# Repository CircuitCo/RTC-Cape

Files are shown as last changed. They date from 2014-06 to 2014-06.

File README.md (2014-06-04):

RTC-Cape
========
The RTC Cape provides time tracking capability for the BeagleBone Black even when the power is lost. This cape features the DS1338 I2C-based real-time clock/calendar and a holder for a coin battery type CR2032. Setup, reading, and setting up time is easy with the provided device tree overlay.

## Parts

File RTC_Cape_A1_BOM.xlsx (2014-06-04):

BOARD NAME: RTC CAPE
REVISION: A1 |  |  |  | LAST UPDATE: | 2014-04-04
PART NUMBER: 999-0004279
ITM | QTY | REF DESIGNATOR | PART NUMBER | DESCRIPTION | MANUFACTURER | MAN P/N
1 | 1 | PCB | 999-0004279 | RTC CAPE | CIRCUITCO
2 | 1 | BH1 | 253-0004977 | HOLDER COINCELL 2032 RETAINRCLIP | MPD | BS-7
3 | 1 | C1 | 123-0001047 | CAP CER 0.1UF 10V 10% X5R 0402 | MURATA | GRM155R61A104KA01
4 | 2 | P8, P9 | 235-0002217 | 46 POS,DUAL,GOLD,.1" | MLE | SSHQ-123-D-08-G-LF
5 | 3 | R1, R2, R3 | 110-0001987 | RES 2.2K OHM 1/16W 5% 0402 SMD | YAGEO | RC0402JR-072K2L
6 | 1 | R4 | RC0402JR-070RL | RES 0.0 OHM 1/16W JUMP 0402 SMD | YAGEO | RC0402JR-070RL
7 | 1 | U1 | 140-0004976 | IC RTC SERIAL 512K 8SOIC | MAXIM | DS1338Z-33+
8 | 1 | Y1 | 145-0003173 | CRYSTAL 32.768KHZ 12.5PF THRU | CITIZEN | CFS308-32.768KDZF-UB

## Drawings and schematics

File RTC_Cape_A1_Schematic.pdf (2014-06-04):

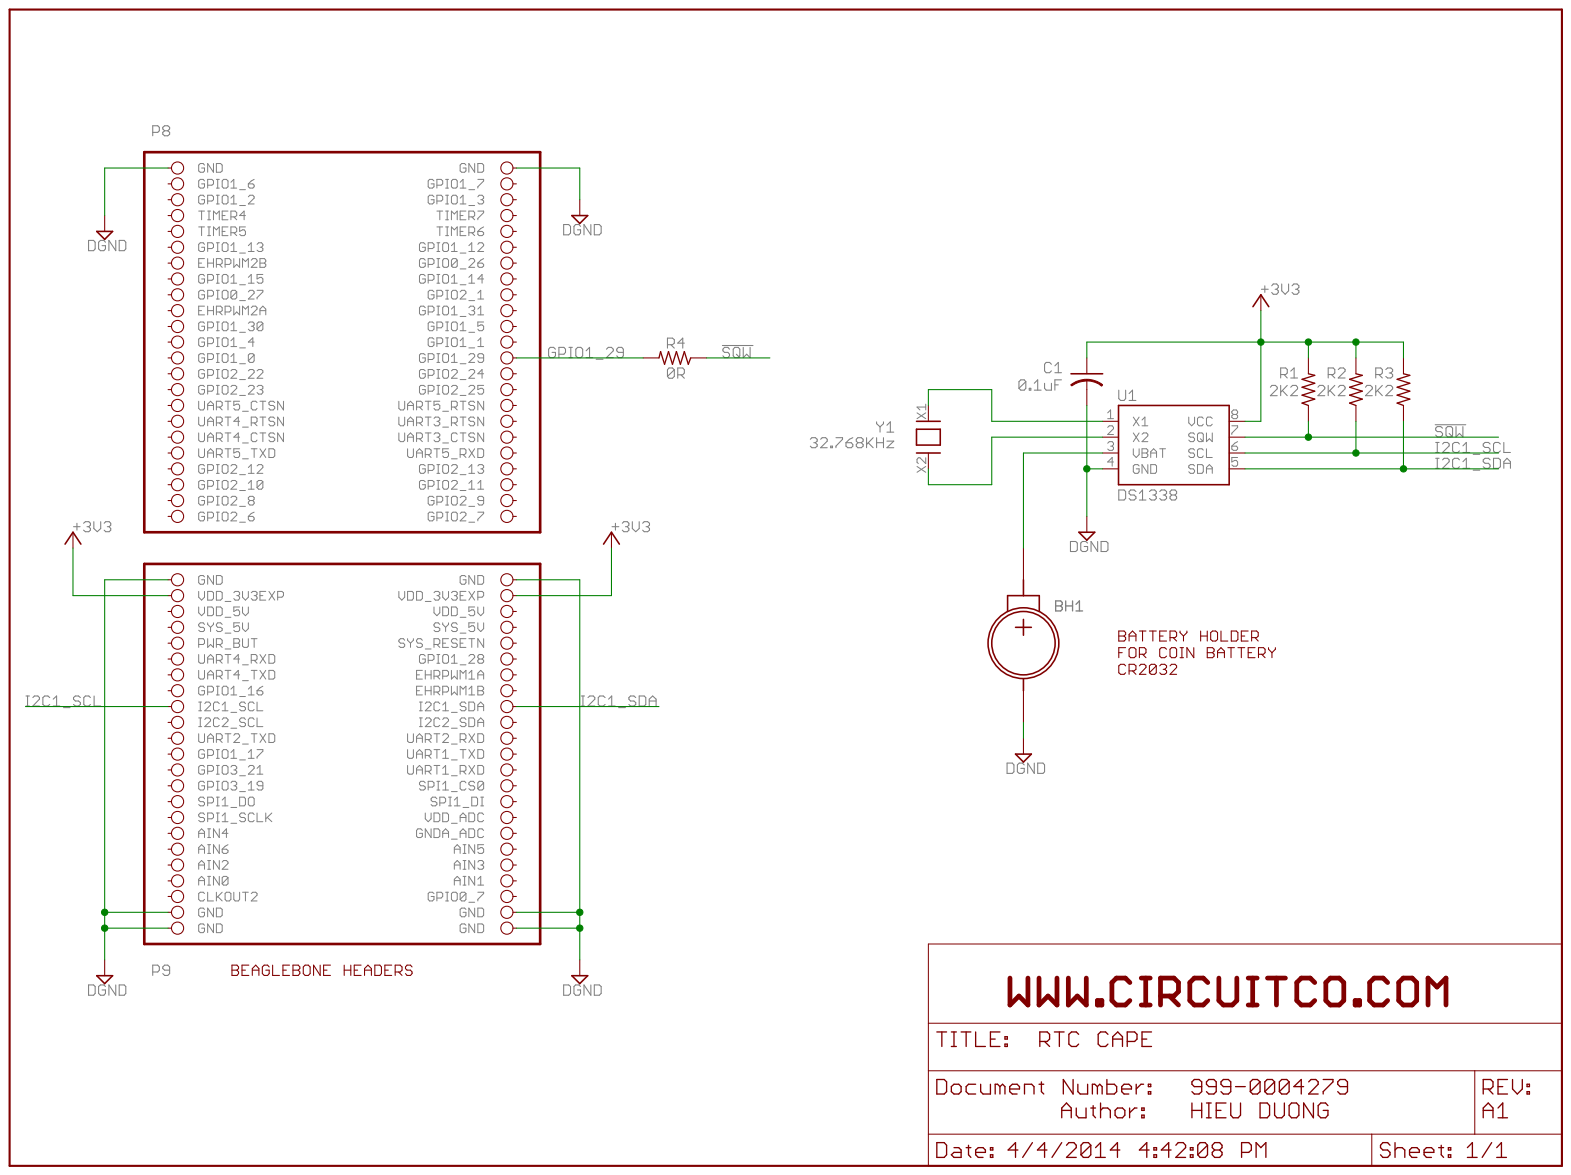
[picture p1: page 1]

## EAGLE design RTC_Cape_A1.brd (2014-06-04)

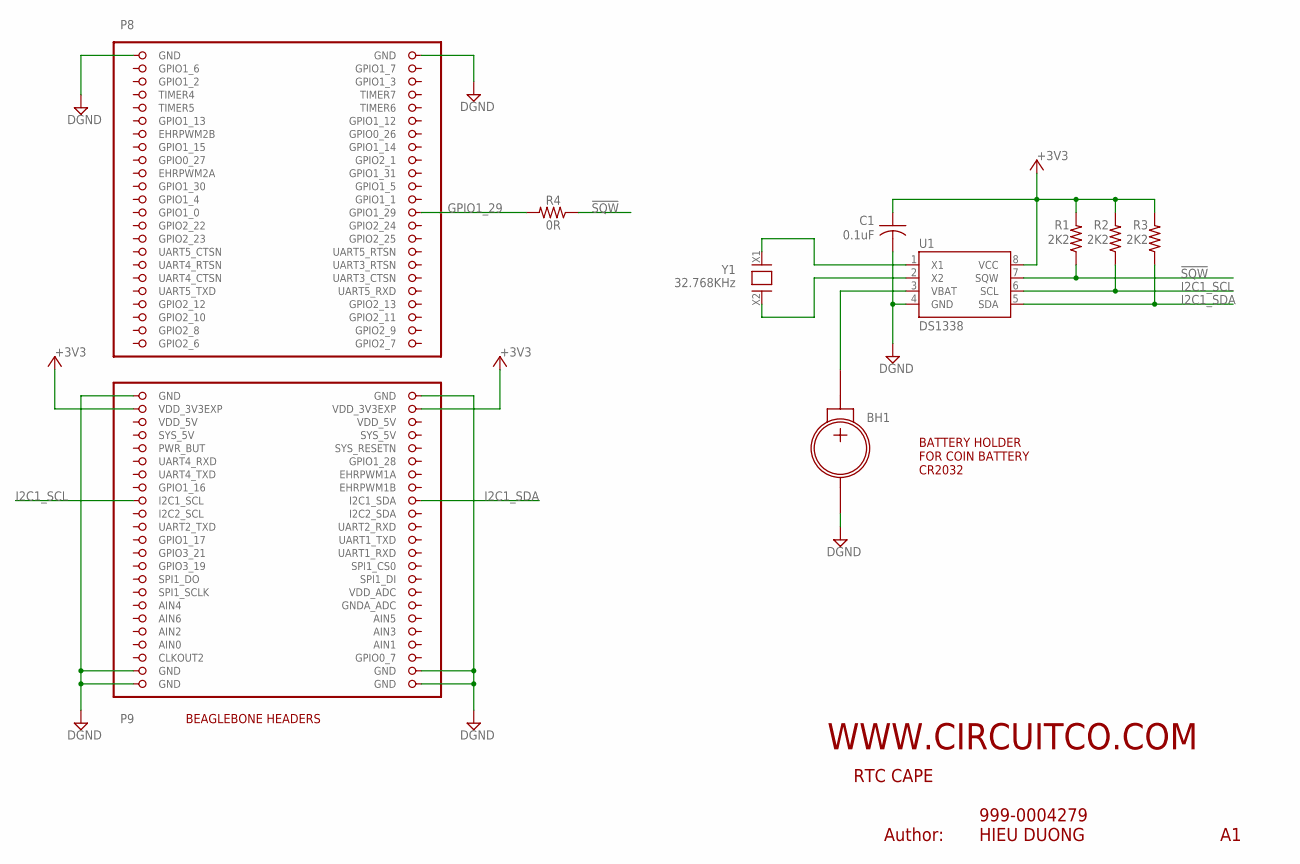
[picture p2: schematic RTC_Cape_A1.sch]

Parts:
BH1: BS-7
C1: 0.1uF; C0402
R1, R2, R3: 2K2; R0402
R4: 0R; R0402
U1: DS1338; MXM-SOIC8-90-0112
U$1: BB_OL_GENPROTO
Y1: 32.768KHz; CRYSTAL-CFS-308-SMD

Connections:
!SQW: R1.1, R4.1, U1.7 (SQW)
+3V3: C1.1, R1.2, R2.2, R3.2, U1.8 (VCC), U$1.49 (VDD_3V3EXP), U$1.50 (VDD_3V3EXP)
AIN0: U$1.85 (AIN0)
DGND: BH1.NEG, C1.2, U1.4 (GND), U$1.1 (GND), U$1.2 (GND), U$1.47 (GND), U$1.48 (GND), U$1.89 (GND), U$1.90 (GND), U$1.91 (GND), U$1.92 (GND)
GPIO1_29: R4.2, U$1.26 (GPIO1_29)
I2C1_SCL: R2.1, U1.6 (SCL), U$1.63 (I2C1_SCL)
I2C1_SDA: R3.1, U1.5 (SDA), U$1.64 (I2C1_SDA)
unnamed: BH1.POS, U1.3 (VBAT)
unnamed: U1.2 (X2), Y1.X2 (2)
unnamed: U1.1 (X1), Y1.X1 (1)
SYS_5V: U$1.53 (SYS_5V)
VDD_5V: U$1.51 (VDD_5V), U$1.52 (VDD_5V)

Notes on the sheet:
BATTERY HOLDER FOR COIN BATTERY CR2032
BEAGLEBONE HEADERS
Author:

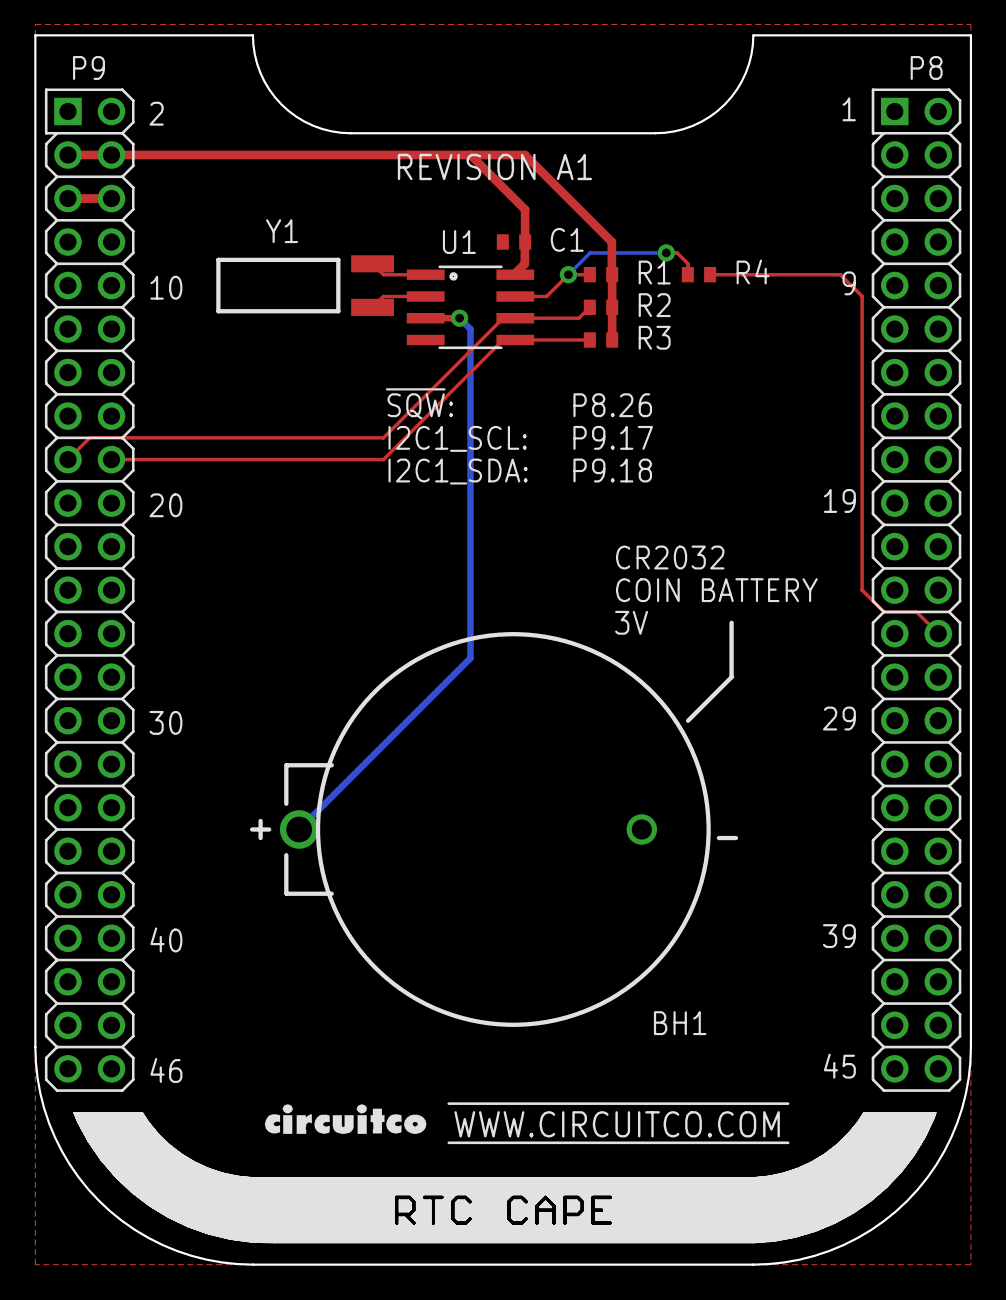
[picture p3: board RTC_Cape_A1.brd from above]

Board: 2 copper layers, 54.6 x 71.8 mm, 12 parts (0 on the bottom side), 10 nets.

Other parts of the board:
DRILEGEND: DRILEGEND
U$2: CIRCUITCO-LOGO
U$3: NEGA-RTC-NAME
